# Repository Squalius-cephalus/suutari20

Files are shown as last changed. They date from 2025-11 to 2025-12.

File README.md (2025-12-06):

## Suutari20
suutari20

Suutari20 is a RP2040 based modular macro keyboard. It uses TRRS sockets and supports 3.5mm jacks from TS to TRRS. Firmware uses QMK with Vial.

**Build guide and information about modules can be found here: https://github.com/Squalius-cephalus/suutari20/wiki/Getting-started**

**Bill of materials - Suutari20**
- 3D printed case
- PCB
- 4x M2xL3xOD3 heatset inserts 
- 4x M2 bolts
- 8x PJ-320A audio sockets
- Raspberry Pi Pico or pin compatible clone

For now most of the information about Suutari20 can be found on this video:

Suutari20 Video (http://www.youtube.com/watch?v=aXpid53uwqs "Modular Macro Keyboard - Suutari20")

TODO:
- Add images
- Add more info about modules

PCB design uses footprints from [ScottoKeebs](https://github.com/joe-scotto/scottokeebs/tree/main/Extras/ScottoKicad "ScottoKeebs") and [kbd library.](https://github.com/foostan/kbd "kbd library.")

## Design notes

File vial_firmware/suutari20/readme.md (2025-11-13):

# suutari20

suutari20

Suutari20 is a RP2040 based modular macro keyboard. It uses TRRS sockets and supports 3.5mm jacks from TS to TRRS.

* Keyboard Maintainer: [squalius-cephalus](https://github.com/squalius-cephalus)
* Hardware Supported: *RP2040 Pi Pico*

Make example for this keyboard (after setting up your build environment):

    make suutari20:vial

Flashing example for this keyboard:

    make suutari20:vial:flash

See the [build environment setup](https://docs.qmk.fm/#/getting_started_build_tools) and the [make instructions](https://docs.qmk.fm/#/getting_started_make_guide) for more information. Brand new to QMK? Start with our [Complete Newbs Guide](https://docs.qmk.fm/#/newbs).

## Bootloader

Enter the bootloader in 2 ways:

* **Physical boot button**: Hold BOOT button down and connect MCU to the PC
* **Keycode in layout**: Press the key mapped to `QK_BOOT` if it is available

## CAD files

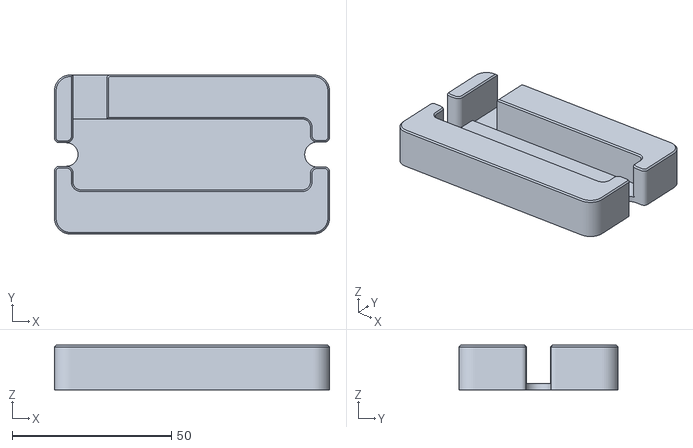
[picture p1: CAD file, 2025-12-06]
case_files/modules/mx_keymodule_holder.stl
86.4 x 50.0 x 14.0

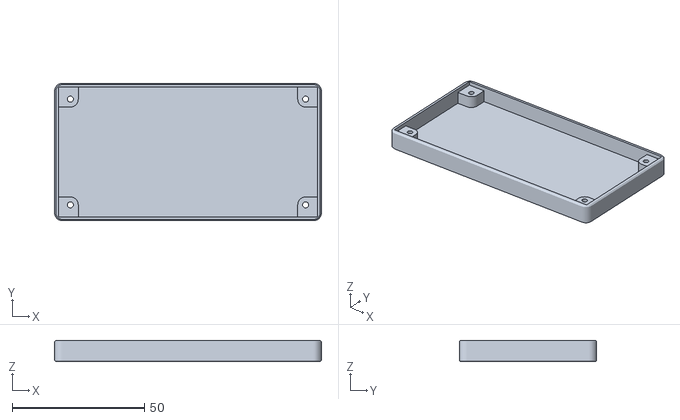
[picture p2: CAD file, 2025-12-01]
case_files/suutari20_case_bottom.stl
101.0 x 52.0 x 8.10

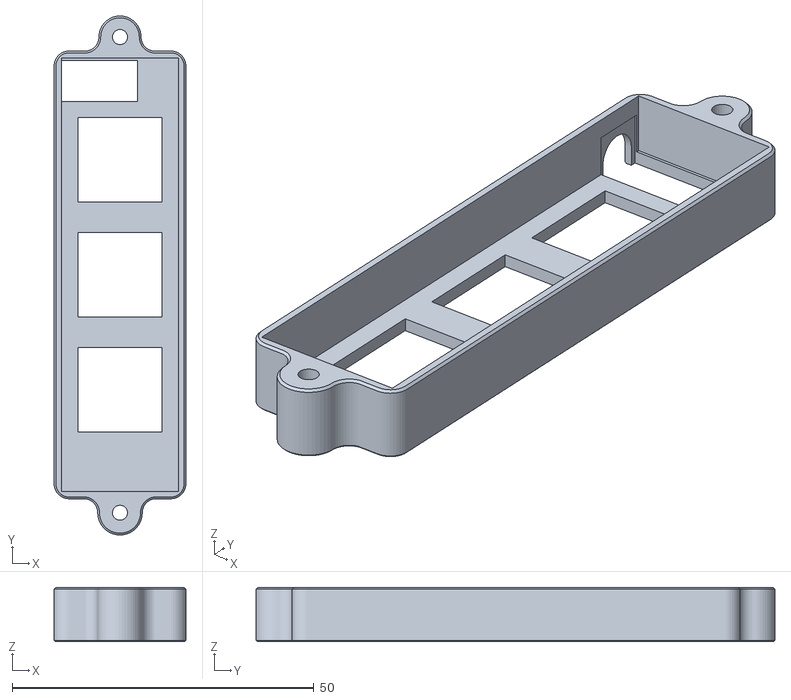
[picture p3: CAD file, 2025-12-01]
case_files/modules/MX_key_module_top.stl
21.9 x 86.0 x 9.00

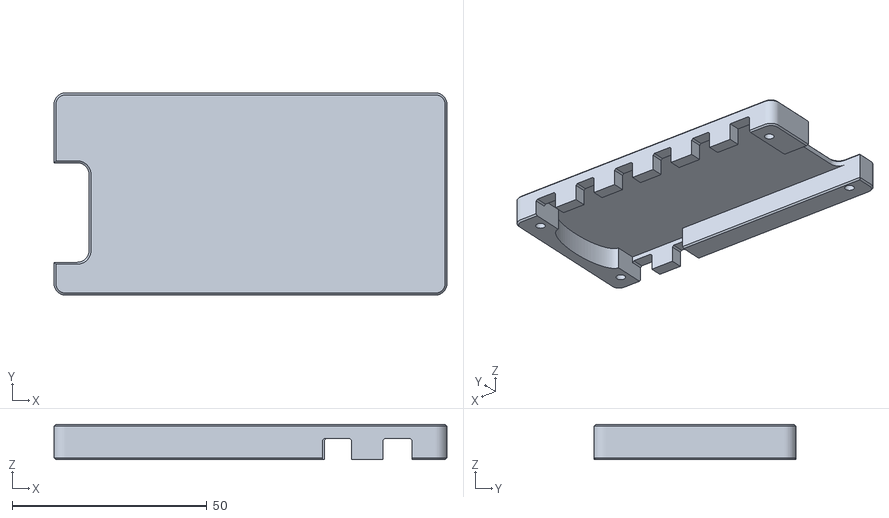
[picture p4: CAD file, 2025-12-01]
case_files/suutari20_case_top.stl
101.0 x 52.0 x 9.10

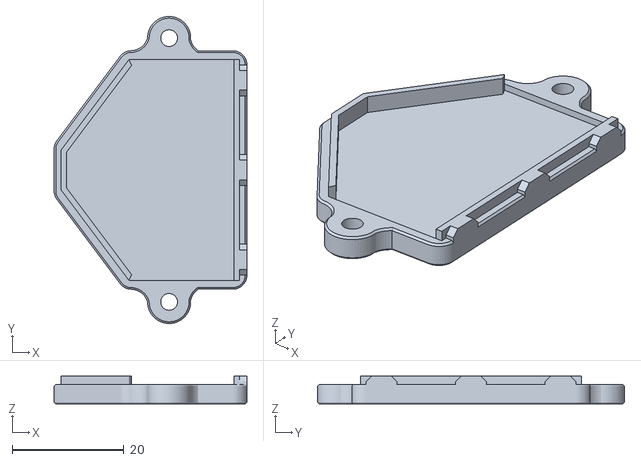
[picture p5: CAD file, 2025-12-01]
case_files/modules/TRRS_splitter_top.stl
34.4 x 54.8 x 5.00

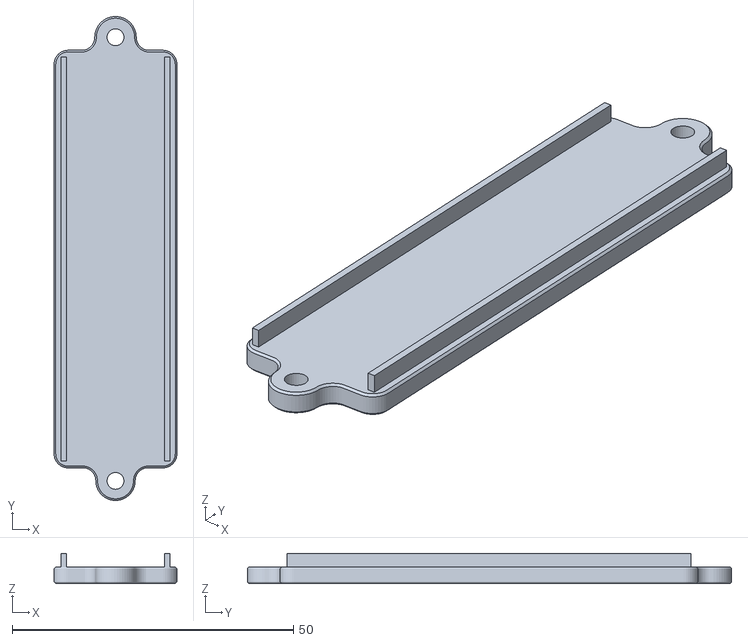
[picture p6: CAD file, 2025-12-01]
case_files/modules/MX_key_module_bottom.stl
21.9 x 86.0 x 5.40

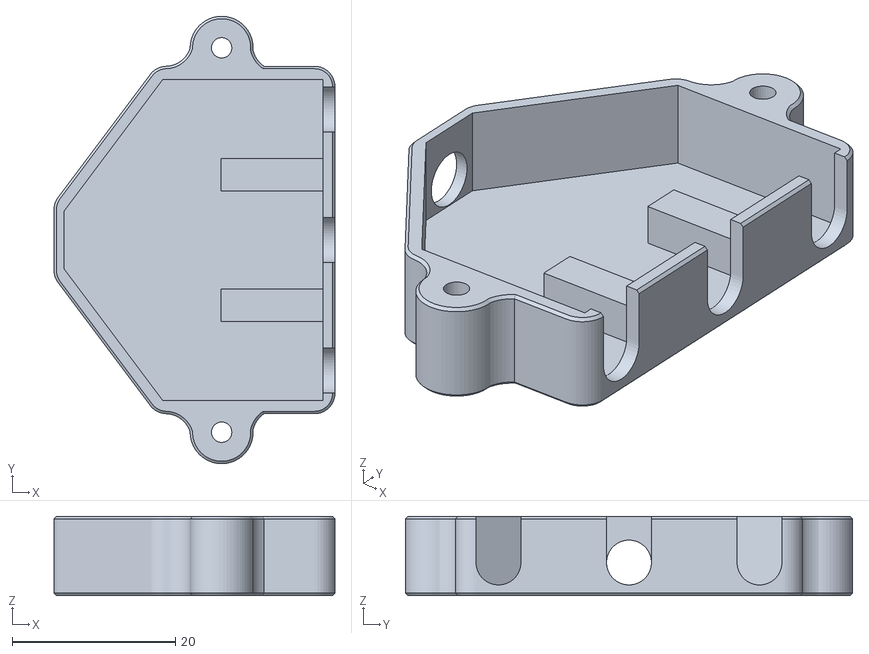
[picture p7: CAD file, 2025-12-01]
case_files/modules/TRRS_splitter_bottom.stl
34.4 x 54.8 x 9.70

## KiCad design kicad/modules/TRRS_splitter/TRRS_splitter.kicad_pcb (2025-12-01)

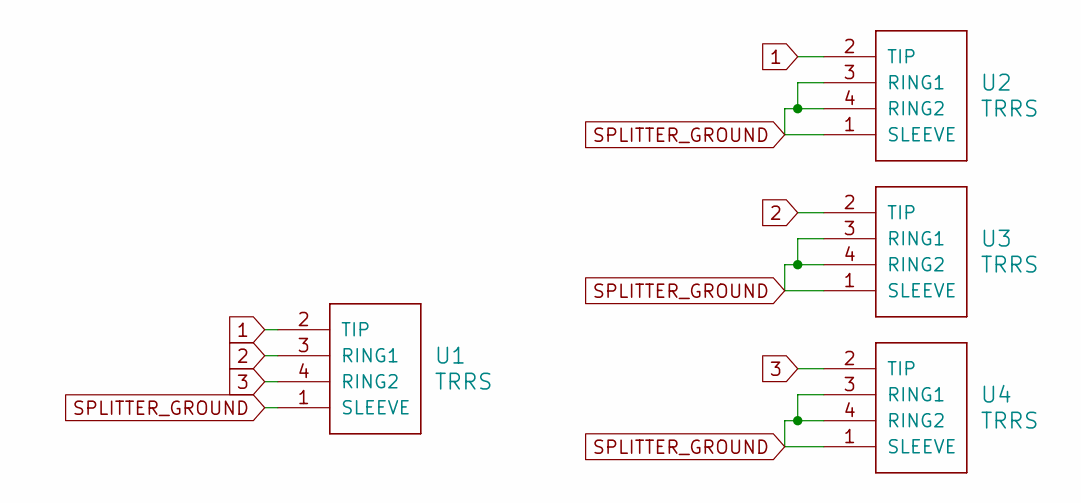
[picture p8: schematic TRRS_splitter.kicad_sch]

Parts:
U1, U2, U3, U4: TRRS; TRRS_PJ-320A

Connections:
1: U1.2 (TIP), U2.2 (TIP)
2: U1.3 (RING1), U3.2 (TIP)
3: U1.4 (RING2), U4.2 (TIP)
SPLITTER_GROUND: U1.1 (SLEEVE), U2.1 (SLEEVE), U2.3 (RING1), U2.4 (RING2), U3.1 (SLEEVE), U3.3 (RING1), U3.4 (RING2), U4.1 (SLEEVE), U4.3 (RING1), U4.4 (RING2)

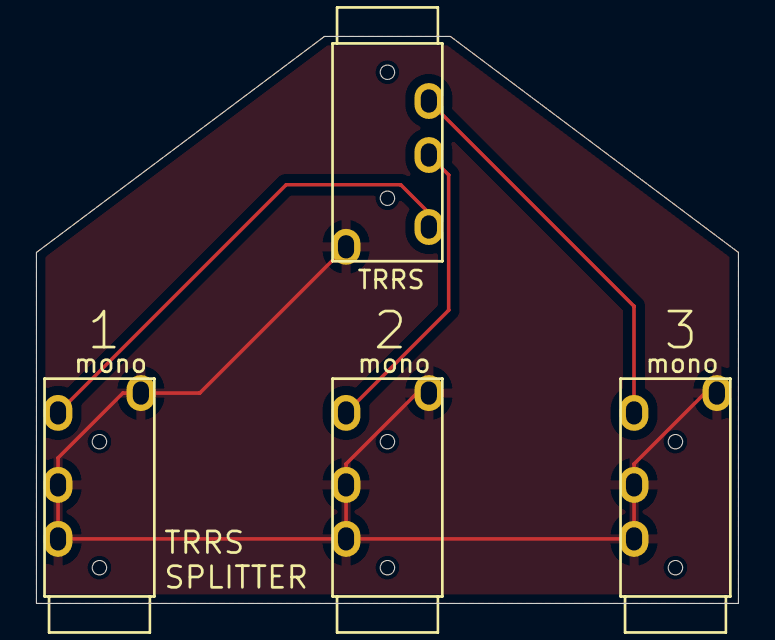
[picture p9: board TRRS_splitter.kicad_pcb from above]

Board: 2 copper layers, 39.0 x 31.5 mm, 4 parts (0 on the bottom side), 4 nets.

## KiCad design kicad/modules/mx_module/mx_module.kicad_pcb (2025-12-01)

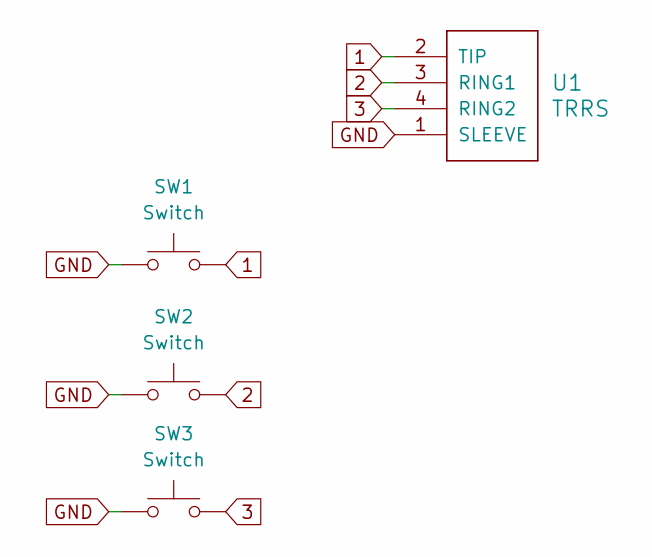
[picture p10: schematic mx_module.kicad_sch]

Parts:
SW1, SW2, SW3: Switch; CherryMX_MidHeight_Hotswap
U1: TRRS; TRRS_PJ-320A

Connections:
1: SW1.2, U1.2 (TIP)
2: SW2.2, U1.3 (RING1)
3: SW3.2, U1.4 (RING2)
GND: SW1.1, SW2.1, SW3.1, U1.1 (SLEEVE)

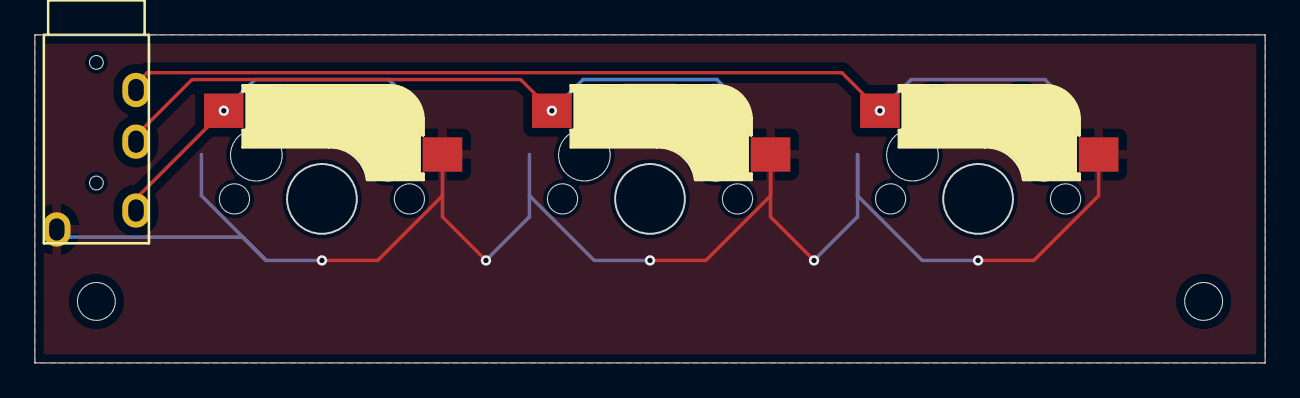
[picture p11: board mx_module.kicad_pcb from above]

Board: 2 copper layers, 71.4 x 19.1 mm, 4 parts (0 on the bottom side), 4 nets.

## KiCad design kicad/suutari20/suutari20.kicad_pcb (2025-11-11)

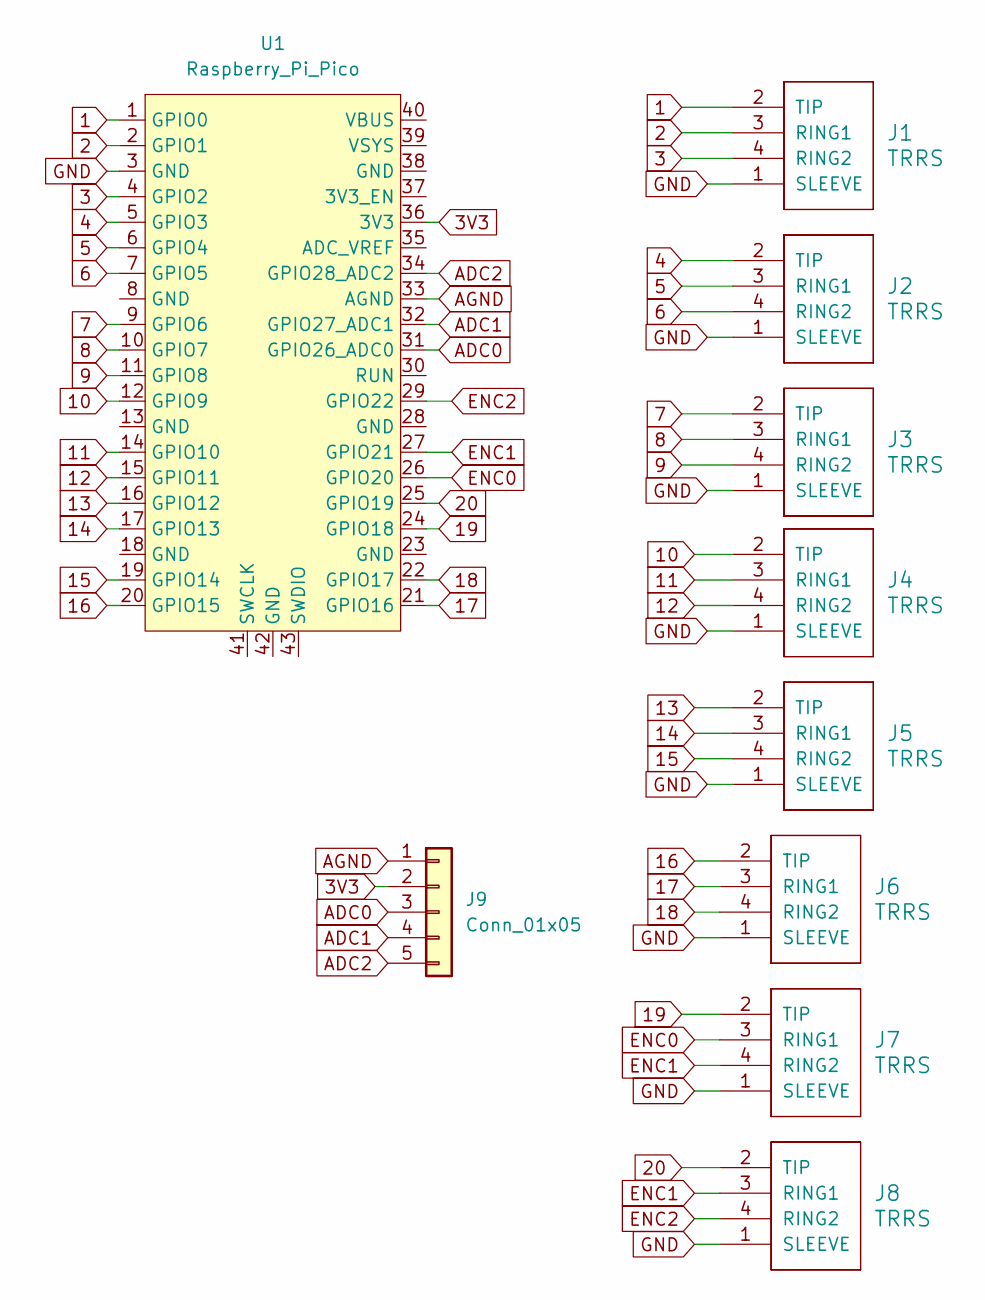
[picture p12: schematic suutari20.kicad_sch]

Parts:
J1, J2, J3, J4, J5, J6, J7, J8: TRRS; TRRS_PJ-320A
J9: Conn_01x05; JST_XH_B5B-XH-A_1x05_P2.50mm_Vertical
U1: Raspberry_Pi_Pico

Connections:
1: J1.2 (TIP), U1.1 (GPIO0)
2: J1.3 (RING1), U1.2 (GPIO1)
3: J1.4 (RING2), U1.4 (GPIO2)
3V3: J9.2, U1.36 (3V3)
4: J2.2 (TIP), U1.5 (GPIO3)
5: J2.3 (RING1), U1.6 (GPIO4)
6: J2.4 (RING2), U1.7 (GPIO5)
7: J3.2 (TIP), U1.9 (GPIO6)
8: J3.3 (RING1), U1.10 (GPIO7)
9: J3.4 (RING2), U1.11 (GPIO8)
10: J4.2 (TIP), U1.12 (GPIO9)
11: J4.3 (RING1), U1.14 (GPIO10)
12: J4.4 (RING2), U1.15 (GPIO11)
13: J5.2 (TIP), U1.16 (GPIO12)
14: J5.3 (RING1), U1.17 (GPIO13)
15: J5.4 (RING2), U1.19 (GPIO14)
16: J6.2 (TIP), U1.20 (GPIO15)
17: J6.3 (RING1), U1.21 (GPIO16)
18: J6.4 (RING2), U1.22 (GPIO17)
19: J7.2 (TIP), U1.24 (GPIO18)
20: J8.2 (TIP), U1.25 (GPIO19)
ADC0: J9.3, U1.31 (GPIO26_ADC0)
ADC1: J9.4, U1.32 (GPIO27_ADC1)
ADC2: J9.5, U1.34 (GPIO28_ADC2)
AGND: J9.1, U1.33 (AGND)
ENC0: J7.3 (RING1), U1.26 (GPIO20)
ENC1: J7.4 (RING2), J8.3 (RING1), U1.27 (GPIO21)
ENC2: J8.4 (RING2), U1.29 (GPIO22)
GND: J1.1 (SLEEVE), J2.1 (SLEEVE), J3.1 (SLEEVE), J4.1 (SLEEVE), J5.1 (SLEEVE), J6.1 (SLEEVE), J7.1 (SLEEVE), J8.1 (SLEEVE), U1.3 (GND)

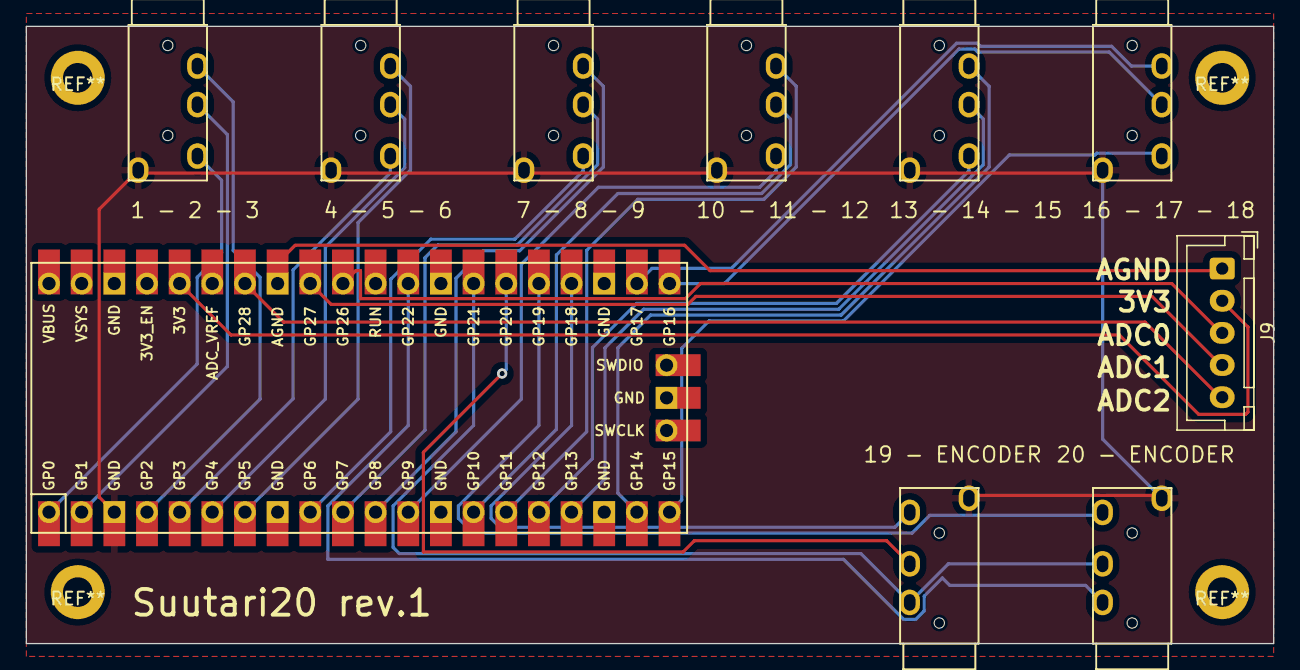
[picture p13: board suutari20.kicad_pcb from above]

Board: 2 copper layers, 97.0 x 48.0 mm, 10 parts (0 on the bottom side), 29 nets.

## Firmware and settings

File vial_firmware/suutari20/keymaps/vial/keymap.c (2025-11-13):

// Copyright 2023 QMK
// SPDX-License-Identifier: GPL-2.0-or-later

#include QMK_KEYBOARD_H

const uint16_t PROGMEM keymaps[][MATRIX_ROWS][MATRIX_COLS] = {
    /*
     * ┌───┐ ┌───┐ ┌───┐ ┌───┐ ┌───┐ ┌───┐
     * │ 1 │ │ 1 │ │ 1 │ │ 1 │ │ 1 │ │ 1 │
     * ├───┤ ├───┤ ├───┤ ├───┤ ├───┤ ├───┤    ┌───┐
     * │   │ │   │ │   │ │   │ │   │ │   │    │   │ Bottom Row Left
     * ├───┤ ├───┤ ├───┤ ├───┤ ├───┤ ├───┤    ├───┤
     * │   │ │   │ │   │ │   │ │   │ │   │    │   │ Bottom Row Right
     * └───┘ └───┘ └───┘ └───┘ └───┘ └───┘    └───┘
     */
    [0] = LAYOUT(
        KC_1,      KC_2,      KC_3,      KC_4,     KC_5,      KC_6,      KC_TRNS,
        KC_TRNS,   KC_TRNS,   KC_TRNS,   KC_TRNS,  KC_TRNS,   KC_TRNS,   KC_TRNS,
        KC_TRNS,   KC_TRNS,   KC_TRNS,   KC_TRNS,  KC_TRNS,   KC_TRNS,   KC_TRNS
    ),

    [1] = LAYOUT(
        KC_TRNS,   KC_TRNS,   KC_TRNS,   KC_TRNS,  KC_TRNS,   KC_TRNS,   KC_TRNS,
        KC_TRNS,   KC_TRNS,   KC_TRNS,   KC_TRNS,  KC_TRNS,   KC_TRNS,   KC_TRNS,
        KC_TRNS,   KC_TRNS,   KC_TRNS,   KC_TRNS,  KC_TRNS,   KC_TRNS,   KC_TRNS
    ),

    [2] = LAYOUT(
        KC_TRNS,   KC_TRNS,   KC_TRNS,   KC_TRNS,  KC_TRNS,   KC_TRNS,   KC_TRNS,
        KC_TRNS,   KC_TRNS,   KC_TRNS,   KC_TRNS,  KC_TRNS,   KC_TRNS,   KC_TRNS,
        KC_TRNS,   KC_TRNS,   KC_TRNS,   KC_TRNS,  KC_TRNS,   KC_TRNS,   KC_TRNS
    ),

    [3] = LAYOUT(
        KC_TRNS,   KC_TRNS,   KC_TRNS,   KC_TRNS,  KC_TRNS,   KC_TRNS,   KC_TRNS,
        KC_TRNS,   KC_TRNS,   KC_TRNS,   KC_TRNS,  KC_TRNS,   KC_TRNS,   KC_TRNS,
        KC_TRNS,   KC_TRNS,   KC_TRNS,   KC_TRNS,  KC_TRNS,   KC_TRNS,   KC_TRNS
    ),

    [4] = LAYOUT(
        KC_TRNS,   KC_TRNS,   KC_TRNS,   KC_TRNS,  KC_TRNS,   KC_TRNS,   KC_TRNS,
        KC_TRNS,   KC_TRNS,   KC_TRNS,   KC_TRNS,  KC_TRNS,   KC_TRNS,   KC_TRNS,
        KC_TRNS,   KC_TRNS,   KC_TRNS,   KC_TRNS,  KC_TRNS,   KC_TRNS,   KC_TRNS
    ),

    [5] = LAYOUT(
        KC_TRNS,   KC_TRNS,   KC_TRNS,   KC_TRNS,  KC_TRNS,   KC_TRNS,   KC_TRNS,
        KC_TRNS,   KC_TRNS,   KC_TRNS,   KC_TRNS,  KC_TRNS,   KC_TRNS,   KC_TRNS,
        KC_TRNS,   KC_TRNS,   KC_TRNS,   KC_TRNS,  KC_TRNS,   KC_TRNS,   KC_TRNS
    ),

    [6] = LAYOUT(
        KC_TRNS,   KC_TRNS,   KC_TRNS,   KC_TRNS,  KC_TRNS,   KC_TRNS,   KC_TRNS,
        KC_TRNS,   KC_TRNS,   KC_TRNS,   KC_TRNS,  KC_TRNS,   KC_TRNS,   KC_TRNS,
        KC_TRNS,   KC_TRNS,   KC_TRNS,   KC_TRNS,  KC_TRNS,   KC_TRNS,   KC_TRNS
    ),

    [7] = LAYOUT(
        KC_TRNS,   KC_TRNS,   KC_TRNS,   KC_TRNS,  KC_TRNS,   KC_TRNS,   KC_TRNS,
        KC_TRNS,   KC_TRNS,   KC_TRNS,   KC_TRNS,  KC_TRNS,   KC_TRNS,   KC_TRNS,
        KC_TRNS,   KC_TRNS,   KC_TRNS,   KC_TRNS,  KC_TRNS,   KC_TRNS,   KC_TRNS
    )


};


#if defined(ENCODER_MAP_ENABLE)
const uint16_t PROGMEM encoder_map[][NUM_ENCODERS][2] = {
    [0] =   { ENCODER_CCW_CW(KC_MS_WH_UP, KC_MS_WH_DOWN), ENCODER_CCW_CW(KC_VOLD, KC_VOLU)  },
    [1] =   { ENCODER_CCW_CW(KC_TRNS, KC_TRNS), ENCODER_CCW_CW(KC_TRNS, KC_TRNS)  },
    [2] =   { ENCODER_CCW_CW(KC_TRNS, KC_TRNS), ENCODER_CCW_CW(KC_TRNS, KC_TRNS)  },
    [3] =   { ENCODER_CCW_CW(KC_TRNS, KC_TRNS), ENCODER_CCW_CW(KC_TRNS, KC_TRNS)  },
    [4] =   { ENCODER_CCW_CW(KC_TRNS, KC_TRNS), ENCODER_CCW_CW(KC_TRNS, KC_TRNS)  },
    [5] =   { ENCODER_CCW_CW(KC_TRNS, KC_TRNS), ENCODER_CCW_CW(KC_TRNS, KC_TRNS)  },
    [6] =   { ENCODER_CCW_CW(KC_TRNS, KC_TRNS), ENCODER_CCW_CW(KC_TRNS, KC_TRNS)  },
    [7] =   { ENCODER_CCW_CW(KC_TRNS, KC_TRNS), ENCODER_CCW_CW(KC_TRNS, KC_TRNS)  }
};
#endif

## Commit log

2025-11-11 Added PCB files and gerber for the main module
    [suutari20.kicad_pcb, suutari20.kicad_sch]
2025-12-01 Added missing STL files and kicad files for the modules
    [MX_key_module_bottom.stl, MX_key_module_top.stl, TRRS_splitter.kicad_pcb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]
